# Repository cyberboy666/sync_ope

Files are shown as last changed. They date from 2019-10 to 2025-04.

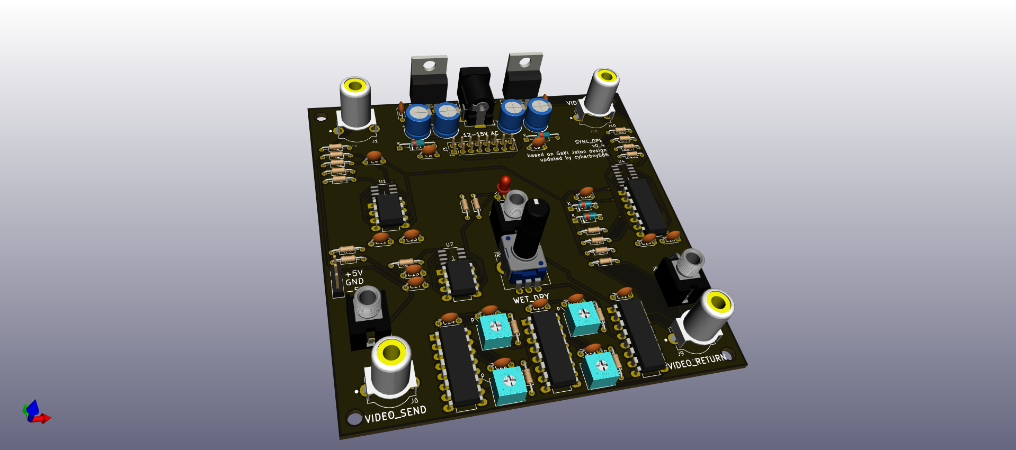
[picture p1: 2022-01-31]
sync_ope_3d.png

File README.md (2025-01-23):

# sync_ope

### effect send + sync restoring circuit - adapted from a gael jaton design



- this circuit is distributed by __UNDERSCORES__ - _an open video hardware label_ : it is available to purchase - as a pcb, kit or assembled unit - at [underscores.shop](https://underscores.shop/sync_ope/)
- the schematic for the circuit can be found [here](/hardware/schematic.pdf)
- the pcb gerber files for the lastest version can be found [here](/hardware/gerber_latest.zip)
- interactive BOM is [here](https://htmlpreview.github.io/?https://github.com/cyberboy666/sync_ope/blob/main/hardware/bom/ibom.html)
- consider [donating](https://opencollective.com/underscores) to the underscores project to help us continue creating for the commons

## description

_sync_ope_ is a companion circuit for analog glitch & circuit bent video instruments. it preserves the sync pulses from the original signal and allows for smooth mixing between clean (dry) and distorted (wet) video. preserving the sync pulses means the distorted video is less likely to drop out (blue screen) when sent to analog video decoders such as in projectors, capture cards and digital tvs

- __knob__ for physical control over dry/wet external effect
- __cv jack (0-1v)__ for sequenced control over dry/wet external effect
- external video send & return over rca or 3.5mm jacks

 __NOTE__ a 12v_dc power supply with 1.5A or greater is required to start the circuit

## demo video

(https://videos.scanlines.xyz/w/eyN4xfUZrG2YHyuf6rk1wZ)

# documentation

this project is fully _open-source hardware_ - all the files required to build it are included in this repo for free. if you have the time and/or skill you can contribute back by collaborating on / testing new designs, improving these docs, making demo videos/other creative content etc. you can also support the project financially by [donating](https://opencollective.com/underscores) directing, or purchasing through the [web shop](https://underscores.shop).

depending on whether you are going fully diy or buying an assembled and tested unit, some of the following guides will be relavent to you. the flow would be:

## ordering parts

<details><summary><b>parts sourcing guide (w/ notes on pcb fabracation )</b> - start here if you are building fully from scatch or have purchased a pcb</summary>

i try to source all the parts i can from either:
- [tayda](https://www.taydaelectronics.com/) ; cheaper for common parts like resistors etc, also good for mechanical parts like switches and buttons
- [mouser](https://www.mouser.de/) ; has lots more options, speciality video ic's, can sometimes cost more (free shipping on orders over 50euros)
- other ; ocationally there will be parts which will need to be sourced elsewhere - usually either aliexpress, ebay or amazon etc...

take a look at the [full_bom](/hardware/bom/full_bom.csv) for this project to see where i am sourcing each part from

## import into tayda

- go to the [tayda quick order](https://www.taydaelectronics.com/quick-order/) and in bottom corner choose _add from file_
- select the file [tayda_bom.csv](./hardware/bom/tayda_bom.csv) in the BOM folder (you will have to download it first or clone this repo)
- after importing select _add to cart_
- __NOTE:__ the minimum value for resistors is 10, so you may need to modify these values to add to cart (or if they are already modified here you will need to see the  full_bom for actual part QTY) 

- OPTIONAL: it is a good idea to add some dip-ic sockets and 2.54pin headers/sockets to your tayda order if you dont have them around already
  
## import into mouser

- go to [mouser bom tool](https://nz.mouser.com/Bom/) and click _upload spreadsheet_
- select the file [mouser_bom.csv](./hardware/bom/mouser_bom.csv) in this folder (you will have to download it first or clone this repo), then _upload my spreadsheet_ and _next_
- ensure that __Mouser Part Number__ is selected in the dropdown above the first row, then _next_, _process_
- if everything looks correct can now put _add to basket_

# ordering pcbs

you can support this project by buying individual pcbs from the [shop](https://underscores.shop). if you would rather have pcbs fabricated from gerbers directly the file you need is [here](/hardware/gerber_latest.zip)

- i get my pcbs fabricated from [jlcpcb](https://cart.jlcpcb.com/quote) - 5 is the minumum order per design
- upload the zip file with the `add gerber file` button
- the default settings are mostly fine - set the __PCB Qty__ and __PCB Color__ settings (you can check that the file looks correct with pcb veiwer)
- it may be best to combine orders with other pcbs you want to have fab'd since the shipping can cost more than the items - also orginising group buys is a good way to distribute the extra pcbs /costs 
  
i often use jlcpcb because they are reliable, cheap and give you an option of colours. remember though that the cheapest Chinese fab houses are not always the most ethical or environmently friendly - if you can afford it consider supporting local companies. 
  
</details>

## assembly guide
  
<details><summary><b>assembly guide</b> - start here if you have purchased a diy kit</summary>

## interactive BOM for build guiding

follow this link to view the [interactive BOM](https://htmlpreview.github.io/?https://github.com/cyberboy666/sync_ope/blob/main/hardware/bom/ibom.html)

## general solder advice

- remember to heat pad first (2-3seconds), then add solder, then continue to heat (1-2seconds)

- Checkout the web-comic [soldering is easy](https://mightyohm.com/files/soldercomic/FullSolderComic_EN.pdf) for more soldering advice

## smd or dip ic option
  
for some of the rarer ic's both smd and dip footprints are on the board - if you are assembling yourself you can choose which of these to source (dont place both!)
 - for the smd parts i would place and solder these first before doing any of the throughhole parts - please make sure these parts are placed facing __downwards__ as indicated on the silkscreen. you can test the continuity of your solder joints with a multimeter on the pin + one on the corresponding dip pad

## assemble guide

- Start by soldering the smallest parts first: resistors, diodes, capacitors and regulators - take note of the direction on the diodes : black bar on component matching black bar on footprint – I place about 10 components in and then solder and clip them
- Next lets do the ic’s/sockets - make sure the direction is correct! place in and fold two corner pins to hold in place, then solder all pins. you can place the ic in now too
- Finally solder in the interface parts: trim_pots & pots, jacks, power barrel. If you are using not using eurorack power supply there is no need to solder anything on j7 (or j3)

## blanking calibration

There is a total of 4 trimpots on the sync_ope board to calibrate the vertical and horizontal blanking pulses – __start by rotating all of them fully clockwise__

## calibrating with an osciloscope

If you have a two channel oscilloscope with edge trigger you can inspect the incoming video signal on one channel and the blanking pulse on the other (trigger on rising edge of this blanking pulse channel)

### calibrate v_blanking (RV3, RV5)

- set the scope width to about 1ms - test the edge detect works by probbing pin3 of u7_lm1881 this should lock the scrolling display to vblanking of the incoming video frame
- next hold pulse probe on _v_blanking_ (__pin10 of u6_hc4538__) - similar to above, the scrolling video should lock over blanking pulse trigger
- starting with top left trim (rv3) allign the rising edge of blanking pulse to the rising edge of video signal by turning rv3 counterclockwise
- next allign falling edge of blanking pulse to falling edge of video signal by turning rv5 counterclockwise

vblanking

### calibrating c_blanking (RV2, RV4):

- set scope width to about 10us - test the edge detect works by probing pin1 of u7_lm1881 this should lock the scrolling display to c_blanking of incoming video line
- next hold pulse probe on c_blanking (pin10 of u5_hc4538) - similar to above, the scrolling video should lock over blanking pulse trigger
- starting with top right trim (rv2) allign the rising edge of blanking pulse to the rising edge of video signal by turning rv2 counterclockwise
- next allign falling edge of blanking pulse to falling edge of video signal by turning rv4 counterclockwise

cblanking

## calibrating without an osciloscope

__start with all trim pots clockwise__ . plug in an effect and have sync_ope mix knob clockwise (wet): notice the square outline of the screen with the effect and the outer parts that are without - this is what we are trying to fill in:

vlcsnap-2022-09-24-21h25m09s377

starting v_blanking with top left - rv3 and then to rv5:

- watching top of screen turn rv3 counterclockwise until effect alligns with viewing area
- watching bottom of screen turn rv5 counterclockwise until effect alligns with viewing area

now c_blanking with top right - rv2 then rv4:

- watching left of screen turn rv2 counterclockwise until effect alligns with viewing area
- watching right of screen turn rv4 counterclockwise until effect alligns with viewing area
  
</details>

## operating guide
  
<details><summary><b>operating guide</b> - start here if you have purchased an assembled unit</summary>
  


- power the unit via the barrel jack with 12v_dc adapter - alternatively you can power it from the eurorack header or +-5v with the side power pins
- plug a composite video source (eg output from a camcorder) into the top left VIDEO_IN jack -> the middle led should light up when a video source input is detected
- plug a composite video display (eg an old tv or easycap capture card) into the top right VIDEO_OUT jack 
- now  with mix knob rotated fully anti-clockwise your source video should be passing through to the display
- plug one of the VIDEO_SEND jacks into the _input_ of your external processing device
- plug one of the VIDEO_RETURN jacks into the _output_ of your external processing device
- now with the mix knob rotated fully clockwise your source video should pass through the external effect device - but with stable sync pulses !
- if you have the gear for it you can sequence this mix knob using the cv jack above it - only the range 0-1v will respond - dont send it negative voltage.
  
## trim pot calibration for pal/ntsc
  
to calibrate the blanking intervals between pal and ntsc there are (rough) markings on the pcb to help you. for any given trimpot:

- rotate it all the way anticlockwise. from this position take the part of cross pointing south-west (7-8oclock) as reference and rotate clockwise until this reference is lined up with the marking (n for ntsc, p for pal)
- if you have an oscilloscope you can calibrate more precisely by connecting the scope inputs to pins 10 of U6 and 10 of U5
- you can also try to calibrate blanking by eye - setting it roughly to the markers and then moving the trimpots slightly to see what happens.

[pic coming soon]

</details>

### more info

<details><summary><b>how the circuit works</b></summary>
  
[coming soon]

</details>

<details><summary><b>contributing guide</b></summary>
  
if you would like to contribute back to these projects in some way but dont know how the best thing (for now) would be to reach out to me directly ( tim@cyberboy666.com or @cyberboy666 on scanlines forum) - i will be happy to help
  
</details>

## credits & more info

This circuit is distributed through UNDERSCORES – open video hardware label – visit [underscores.shop](https://underscores.shop) for more info

The pcb was designed using KICAD , the booklet was created in LibreOffice Draw

Everything from gerbers, cad files, panels and documentation is freely available online and distributed under CC-BY-SA / open-source licenses – help us contribute to the commons !

Ask any questions or start discussions related to this project on the [scanlines.xyz](https://scanlines.xyz) forum – an online community space dedicated to diy av / electronic media art

You can contact me directly at tim (at) cyberboy666 (dot) com 
Please get in touch if you are interested in hosting a workshop !



Thanks to Gael Jaton for sharing your designs and knowledge. to Bastien Lavaud for circuit advice, always. To Guergana Tzatchkova for booklet design inspiration. To Ben Caldwell for project advice. To everyone who has or will contribute ♥♥♥

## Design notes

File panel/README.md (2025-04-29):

# enclosure guide

we now offer ~~two~~ one kind of enclosures for this project:

- __stand-alone enclosure__ - made from a front and back panel, plus screws and standoffs



- ~~__eurorack enclosure__ - made from just a front panel, plus screws and standoffs to mount in a eurorack case~~

currently not offering sync_ope eurorack panels due to [this issue](https://github.com/cyberboy666/sync_ope/issues/9) with circuit requiring >1.5A to start the rails - which is more than many eurorack supplies can give. instead i am working on an improved eurorack version of this circuit - coming soon!

you can support these projects by getting enclosure kits directly through [underscores.shop](https://underscores.shop) - [standalone](https://underscores.shop/product/standalone-enclosure-kit-for-sync_ope/) - _if ordered with an assembled unit we will also assemble the enclosure for you also_

# diy part sourcing

## panel fabrication

included in this repo are the cad files needed to create your own panels. they are designed in kicads pcbnew - so open the `.kicad_pcb` file to edit them directly. 

you can also use the exported `gerber` files (here they are combined in `.zip`) to get panels fabricated in __fr4__ at a pcb house like the ones we sell. (these usually have a minimum order of 5 or 10)  

another option for diy fabrication is using a lasercutter to cut the panels in wood or acrylic. this is what i do when prototyping panels so you should find some exports in `svg` or `dxf` that are laser ready. _note that the `edgecut` layer is for cutting out and the `silkscreen` layer is for the panel markings. you may need to edit these files or export directly from pcbnew to suit the cutter you are using_

it would also be possible to import these panel files into a sketch in 3d cad program like __freecad__ to create a 3d enclosure for 3d printing... however this is not something i have files prepared for

## 3d printing

i use some custom modelled switch and pot caps for my enclosure kits. you can print these yourself or upload them to a 3d printing fabrication service.

## enclosure kit BOM

things like screws and standoffs can be sourced from lots of places. i will link my source as an example although these links often expire. you could even 3d print your own standoffs from the _id/od_ and length (inner diameter 3.2mm, outer diameter 5mm)

### standalone enclosure

item | source
--- | ---
Front panel | [sync_ope_default_panel_for_v1_0_1_mk_ii.zip](https://github.com/cyberboy666/sync_ope/blob/main/panel/default_panel/sync_ope_default_panel_for_v1_0_1_mk_ii.zip)
Back panel | [back_panel.zip](https://github.com/cyberboy666/sync_ope/blob/main/panel/back_panel/back_panel.zip)
Rubber feet x4 | [aliexpress](https://www.aliexpress.com/item/1005005287385986.html?pdp_ext_f=%7B%22sku_id%22:%2212000032498489269%22%7D)
Pot cap x1 | 3d printed from [stl file](https://github.com/cyberboy666/enclosure_kit_commons/blob/main/cap_pot_6mm_shaft/cap_pot_star_single_r2.8.stl)
M3-25mm screw x4 | [aliexpress](https://www.aliexpress.com/item/1005002364189187.html?pdp_ext_f=%7B%22sku_id%22:%2212000020354274907%22%7D)
M3 nut x4 | [aliexpress](https://www.aliexpress.com/item/1005007502691265.html?pdp_ext_f=%7B"sku_id":"12000041089836836"%7D)
m3-13mm standoff x4 (front) | [aliexpress](https://www.aliexpress.com/item/1005003086579258.html?pdp_ext_f=%7B"sku_id":"12000023995222164"%7D)
m3-5mm standoff x4 (back) | [aliexpress](https://www.aliexpress.com/item/1005003086579258.html?pdp_ext_f=%7B"sku_id":"12000023995222156"%7D)

## enclosure assembling

these enclosures are assemlbed by creating a stack of front-panel -> circuit -> back-panel using the screws and standoffs. where the front standoffs go between front panel and pcb and back standoff go between back panel and pcb. the m3 hex holds it together from the bottom.

i find it easiest to hold circuit on its side and work around one screw at a time:

- first place the front standoff between front panel and pcb
- then put the screw through holding them together
- next place back standoff on screw followed by back panel and hex
- then repeat for other 3 corners

tweezers can be helpful to pick and place the standoffs and also to tighten the m3 hexs

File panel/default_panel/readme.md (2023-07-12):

# sync_ope default_panel notes

- the mounting holes fit m3 screws
- 25mm screws will fit front_panel, pcb and back_plate
- the front_panel mounts to pcb with 12mm standoffs
- will need to lie large caps and regulators down to fit panel
- blanking calibration trimpots can still be set with tool such as screwdriver
- the default potentiometers in underscores BOMs have 12mm shaft lengths - consider replacing these with >17mm shaft length alternatives if you plan to use it with a panel

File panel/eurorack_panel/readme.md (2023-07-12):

# sync_ope eurorack_panel notes

- the mounting holes fit m3 screws
- the front_panel mounts to pcb with 12mm standoffs
- will need to lie large caps and regulators down to fit panel
- blanking calibration trimpots can still be set with tool such as screwdriver
- this circuit has footprint for eurorack power header to be soldered to bottom of pcb
- this panel is 20HP
- the default potentiometers in underscores BOMs have 12mm shaft lengths - consider replacing these with >17mm shaft length alternatives if you plan to use it with a panel

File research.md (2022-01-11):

# research

# inital idea and brainstorm

### "real-time-analog-video-send-return-sync-restoring-mixer"

Sync-Ope is an analog video circuit project for sync signal stripping, hard glitch visible signal, mixing dry/wet signal and sync restoring.
Work for both with NTSC/PAL video signals. Dev discussion thread here : https://scanlines.xyz/t/sync-ope-sync-restoring-circuit-next-revision-ideas  

This act as a "video inserter"/ TBK (time base keeper). Basically it split video signal input between 'pulseSync+burst' and visible lignes signal , then sum its before provide video out. It allow to hard glitch the visible signal (with custom passive and active circuits, mechanical switching, body contact, analog guitar effects...) without touching sync part. It's design around a LM1881 sync separator and a LT1251CN CV mixer which allow a kind of "dry/wet" knob and control voltage from video/audio modules (0 to 1V scale).  
video send/receive connexions act as a send/return loop to input/output your custom effect circuit.  
For more details on construction, please see README file of KiCad folder : https://github.com/gaeljaton/Sync-Ope/tree/master/kicad-files  
  
STATUT :   
-Schematic ok 
-general tests ok  
-PCB V.0.2 NEED REV!    
  
TODO :  
*Stress tests of limiting diodes at video receive (return) inlet, searching for better components (x3 fast diodes 0.7V reversed instead of the zener 1.8V, lower Vdrop for Schottky diode ?)  
*better clamping to blanking level design, actual one crush a bit the burst! affecting colors... => LOGIC GATE DELAY SIGNAL (based CD4069 hex inverter -tested OK!)   
*Negative voltage protection to CV input mixer J5  
*tutorial/review videos  
*PCB design V.0.3 (smaller version - 80x80mm, remove "video send" grounded when unplugged)  
*Eurorack module version, all in line design, 4 to 6 HP

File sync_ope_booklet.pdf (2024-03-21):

### cyberboy666 & underscores.shop present a circuit adapted from gael jaton design

# sync_ope

## effect send and sync restoring circuit

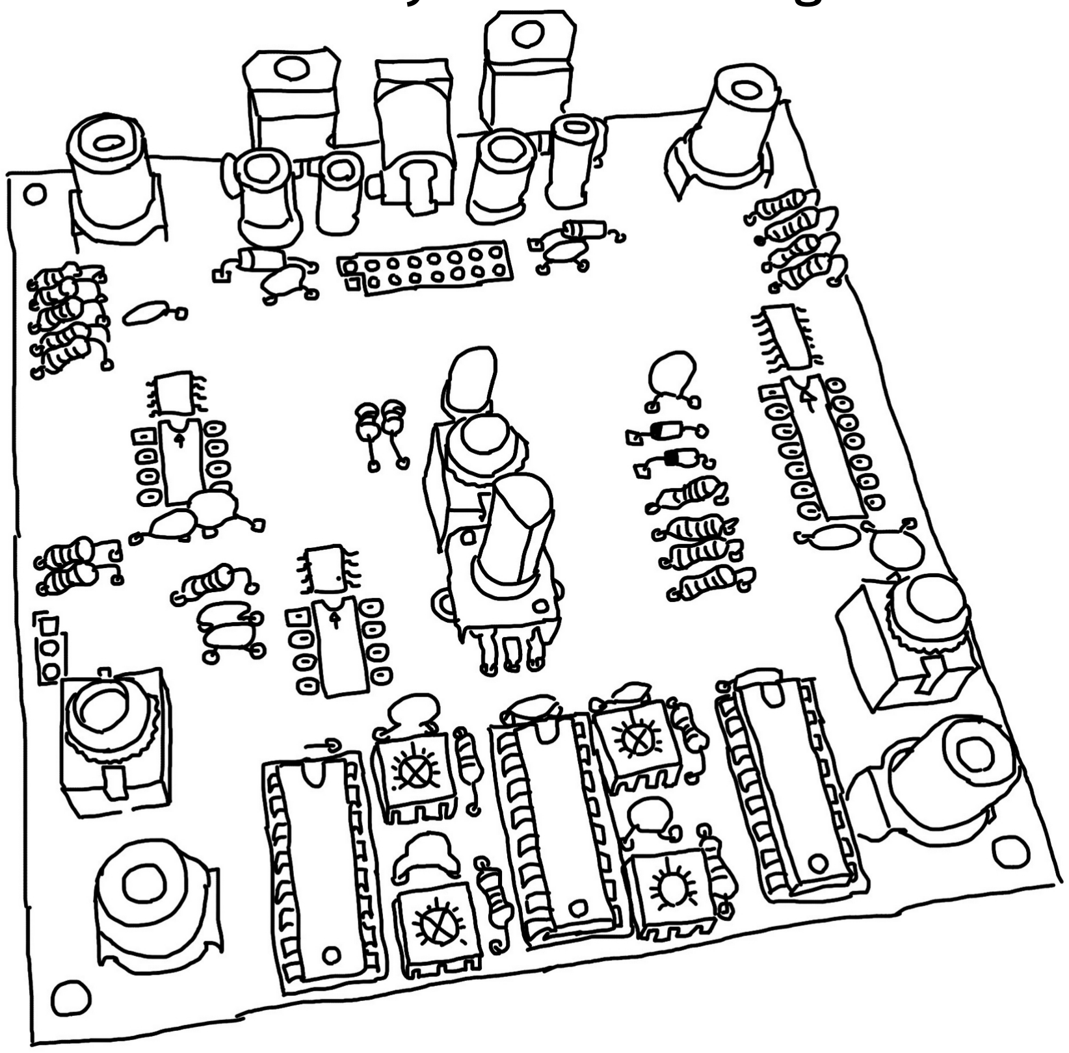
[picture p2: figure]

## instruction manual and build guide

## V1_1_0

View this project online at underscores.shop/sync_ope

# DESCRIPTION

sync_ope is a companion circuit for analog glitch & circuit bent video instruments. it preserves the sync pulses from the original signal and allows for smooth mixing between clean (dry) and distorted (wet) video.

preserving the sync pulses means the distorted video is less likely to drop out (blue screen) when sent to analog video decoders such as in projectors, capture cards and digital tvs

features

- knob for physical control over dry/wet external effect
- cv jack (0-1v) for sequenced control over dry/wet external effect
- external video send & return over rca or 3.5mm jacks

composite
video input

composite
video output

12v dc power input

(2.1mm barrel center positive)

external
effect send
(over 3.5mm
or rca jack)

external

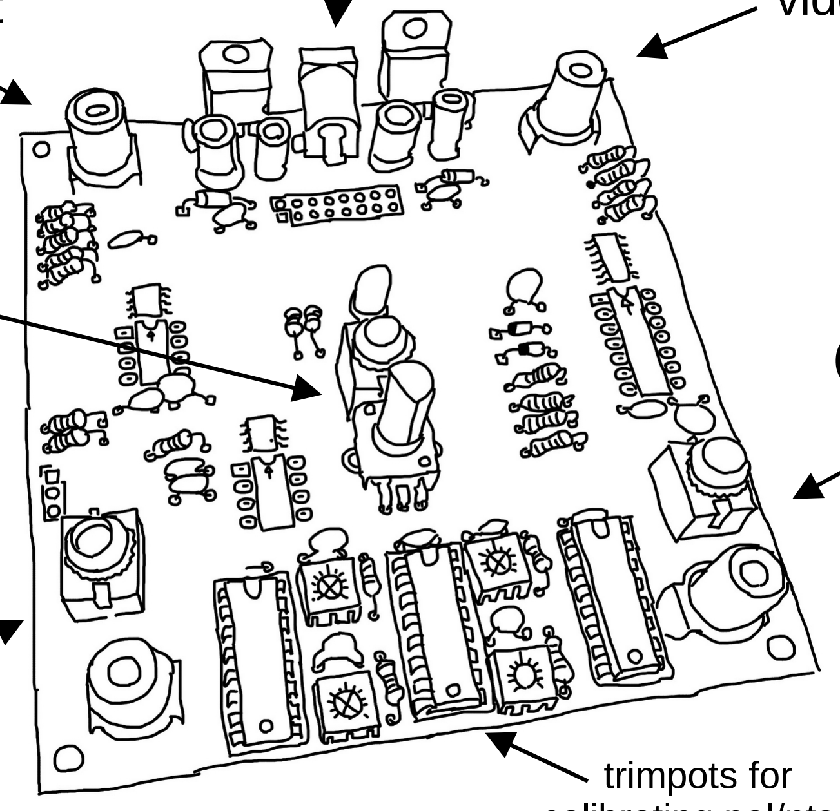
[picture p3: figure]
trimpots for

effect return
(over 3.5mm
or rca jack)

knob and cv
control over
dry/wet
external effect

calibrating pal/ntsc

# BACKGROUND

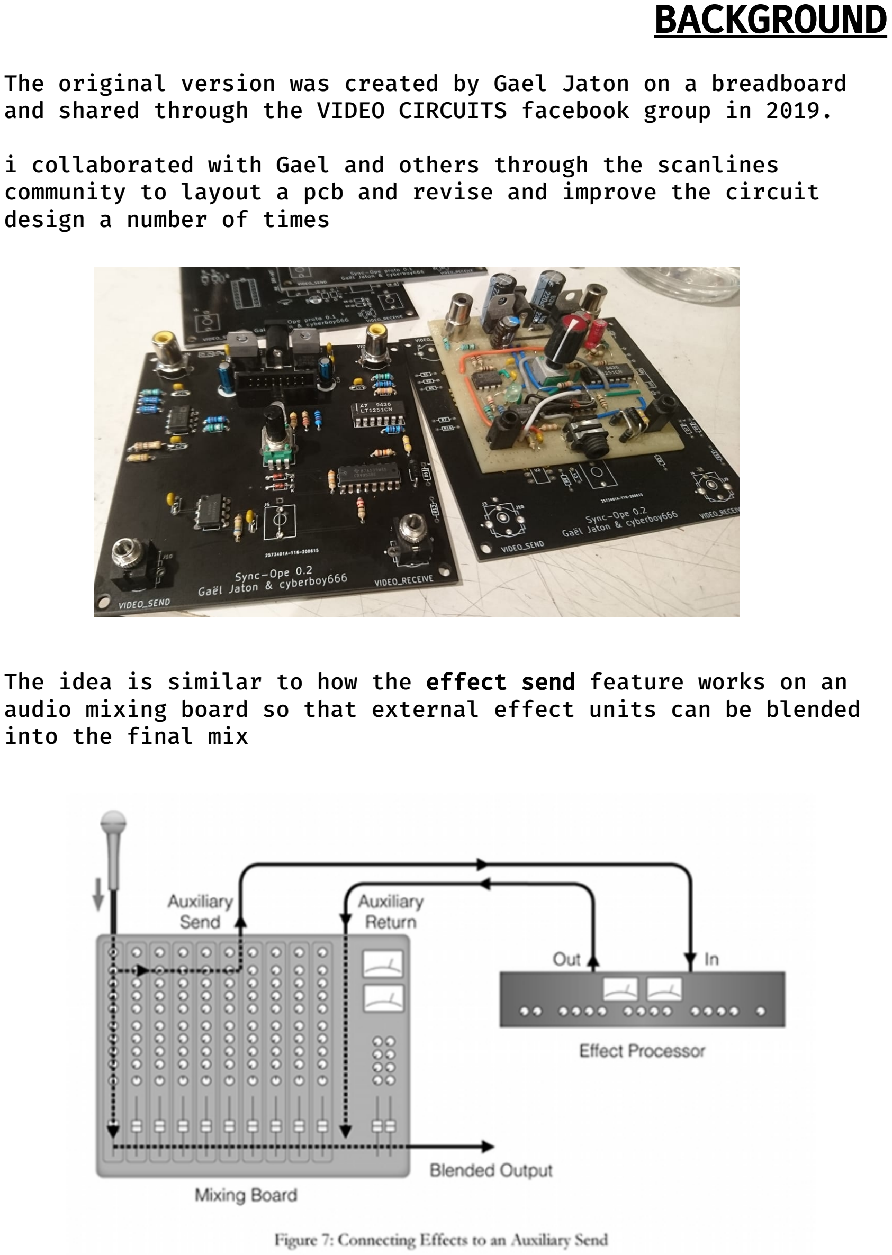
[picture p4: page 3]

The original version was created by Gael Jaton on a breadboard and shared through the VIDEO CIRCUITS facebook group in 2019.

i collaborated with Gael and others through the scanlines community to layout a pcb and revise and improve the circuit design a number of times

The idea is similar to how the effect send feature works on an audio mixing board so that external effect units can be blended into the final mix

# OPERATING INSTRUCTIONS

Power supply

This circuit needs +5v & -5v to operate. As of v1_0_0 there is circuitry on the board to convert standard 12vdc power input from barrel jack to this format. Alternatively if you are using eurorack it can take this +12v directly from this rail

Older versions <= v0_5_1 of the circuit needed 12-15v AC input on the power barrel_jack to generate the +-5v supplies

Connecting ins, outs & the external effect

- plug your composite video source (eg output from a camcorder) into the top left VIDEO_IN jack -> the middle led should light up when a video source input is detected
- Connect your composite video display (eg an old tv or easycap capture card) into the top right VIDEO_OUT jack - now with mix knob rotated fully anti-clockwise your source video should be passing through to the display
- plug one of the VIDEO_SEND jacks into the input and one of the VIDEO_RETURN jacks from the output of your external processing device
- now with the mix knob rotated fully clockwise your source video should pass through the external effect device - but with stable sync pulses !
- if you have the gear for it you can sequence this mix knob using the cv jack above it - 0-1v will cover full range - dont send it negative voltage.

blanking calibration

There is a total of 4 trimpots on the sync_ope board to calibrate the vertical and horizontal blanking pulses – start by rotating all of them fully clockwise

If you have a two channel oscilloscope with edge trigger you can inspect the incoming video signal on one channel and the blanking pulses on the other (see j11 for blanking breakout pins)

Starting from top-left and working down - first slowly turn the trim pots counterclockwise until the rising and falling edges align with blanking on the video signal

If you do not have a scope you can roughly calibrate
In same way by looking at the video output with effect knob fully on – for each pot align effect with an edge of screen: RV3 – top, RV4 – bottom, RV2 left, RV4 right

Find more info for calibration on project github page

wet effect

dry effect

wet effect

# BUILD INSTRUCTIONS

It is highly recommended to use the interactive BOM to help with placement on this build – type kutt.it/ElOPGl into a browser or find the links from the github page

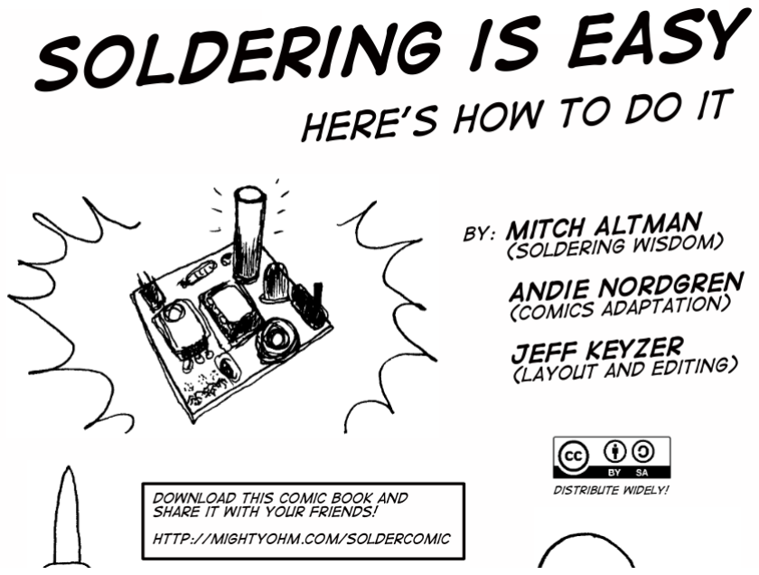
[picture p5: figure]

smd or dip ic option

for some of the rarer ic's both smd and dip footprints are on the board - if you are assembling yourself you can choose which of these to source (dont place both!)

for the smd parts i would place and solder these first before doing any of the throughhole parts - please make sure these parts are placed facing downwards as indicated on the silkscreen. you can test the continuity of your solder joints with a multimeter on the pin + one on the corresponding dip pad

assembling

- Start by soldering the smallest parts first: resistors, diodes, capacitors and regulators - take note of the direction on the diodes : black bar on component matching black bar on footprint – I place about 10 components in and then solder and clip them
- Next lets do the ic’s/sockets - make sure the direction is correct! place in and fold two corner pins to hold in place, then solder all pins. you can place the ic in now too
- Finally solder in the interface parts: trim_pots & pots, jacks, power barrel. If you are not using eurorack power supply there is no need to solder anything on j7 (or j3) note on soldering: remember to heat pad first (2-3seconds), then add solder, then continue to heat (1-2seconds)

Checkout the web-comic
soldering is easy for more soldering advice

# HOW THE CIRCUIT WORKS

A composite video signal is made up of two parts:

visible image data - which tell the tv at any given point how bright the image should be

sync & blanking data – offscreen pulses which help the tv align new lines and frames so they are in sync with each other

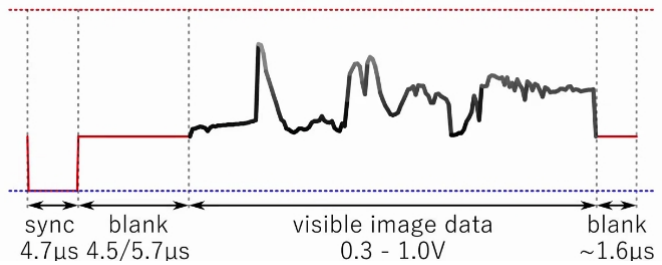
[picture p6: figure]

A digital video display will load this analog signal into its buffer – and needs the sync & blanking to do this correctly. If the sync & blanking pulse is corrupted then it will ‘blue screen’ and show nothing

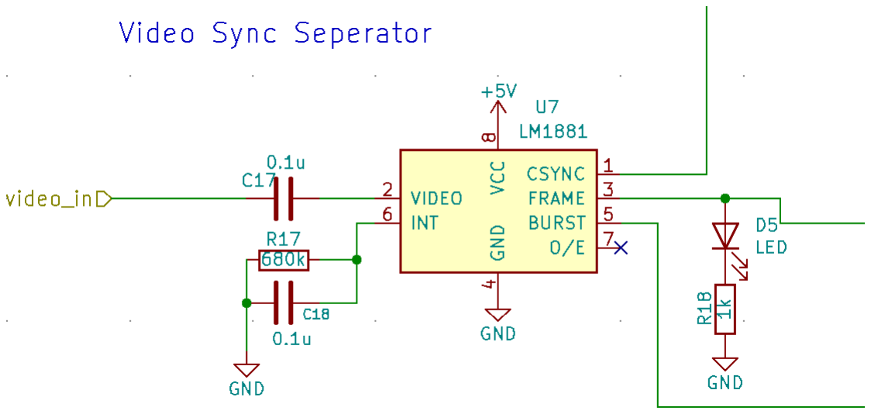
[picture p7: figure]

LM1881 is a video ic that can separate the sync & blanking part of the video signal

# HOW THE CIRCUIT WORKS CONTINUED

LT1251 is a video crossfader ic that creates an output signal as a mix between two inputs (A & B).

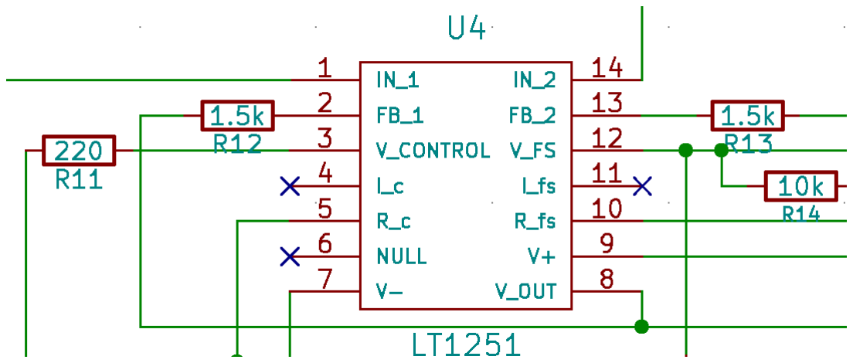
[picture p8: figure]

Output from the sync detecting ic is used to set the ‘crossfader’ position of video output – when video signal is in sync & blanking range the output will use the clean signal (A) – this ensures that no matter how corrupted the visible image data becomes, the sync & blanking data of the output video signal will always be clean

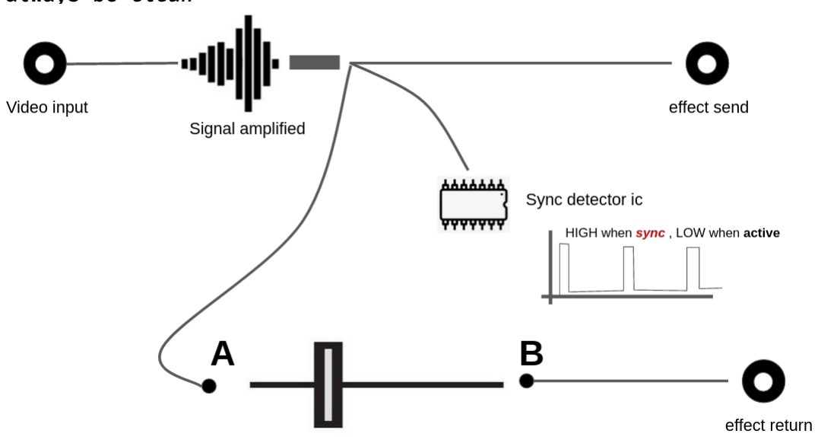
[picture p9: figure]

Then when signal is in the visible image range the knob/cv jack will position the crossfader between A and B (ie decide how much of clean vs wet signal to show in visible image)

# CREDITS AND MORE INFO

This circuit is distributed through UNDERSCORES – open video hardware label – visit underscores.shop for more info

The pcb was designed using KICAD , this booklet was created in LibreOffice Draw

Everything from gerbers, cad files, panels and documentation is freely available online and distributed under CC-BY-SA / open-source licenses – help us contribute to the commons !

Ask any questions or start discussions related to this project on the scanlines.xyz forum – an online community space dedicated to diy av / electronic media art

You can contact me directly at tim (at) cyberboy666 (dot) com Please get in touch if you are interested in hosting a workshop !

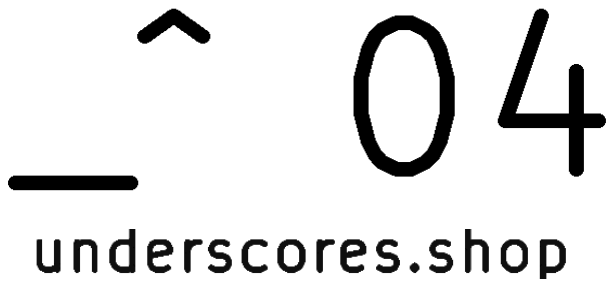
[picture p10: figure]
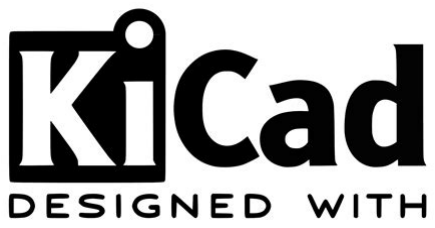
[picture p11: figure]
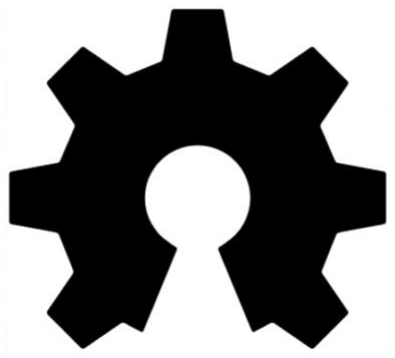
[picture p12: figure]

Thanks to Gael Jaton for sharing your design and knowledge. to Bastien Lavaud for circuit advice, always. To Guergana Tzatchkova for booklet design inspiration. To Ben Caldwell for project advice. To everyone who has or will contribute ♥♥♥

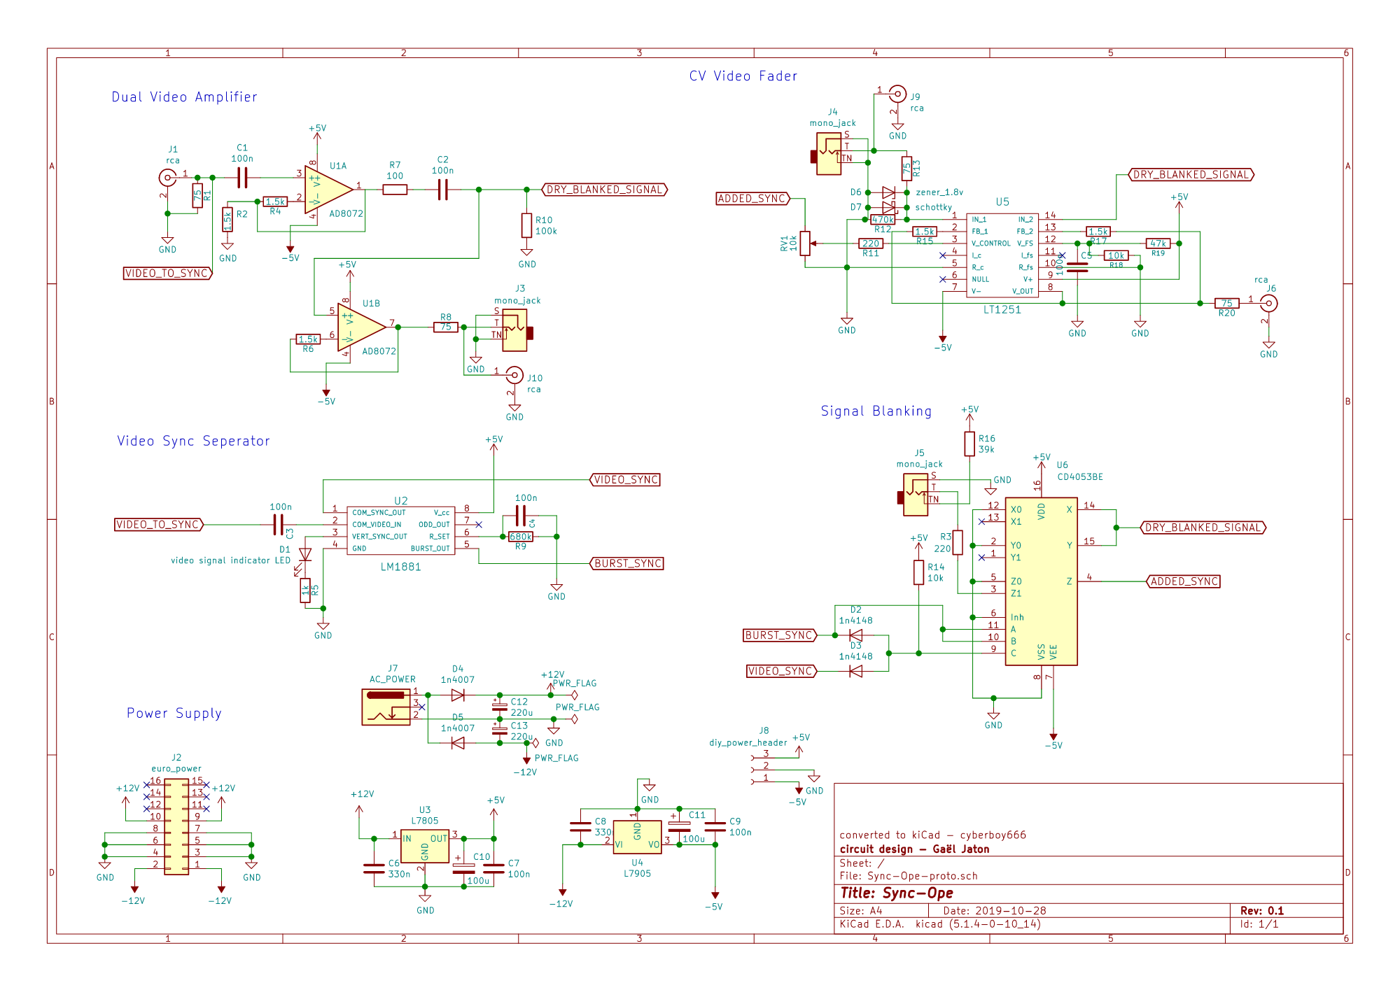
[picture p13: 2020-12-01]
schV01.png

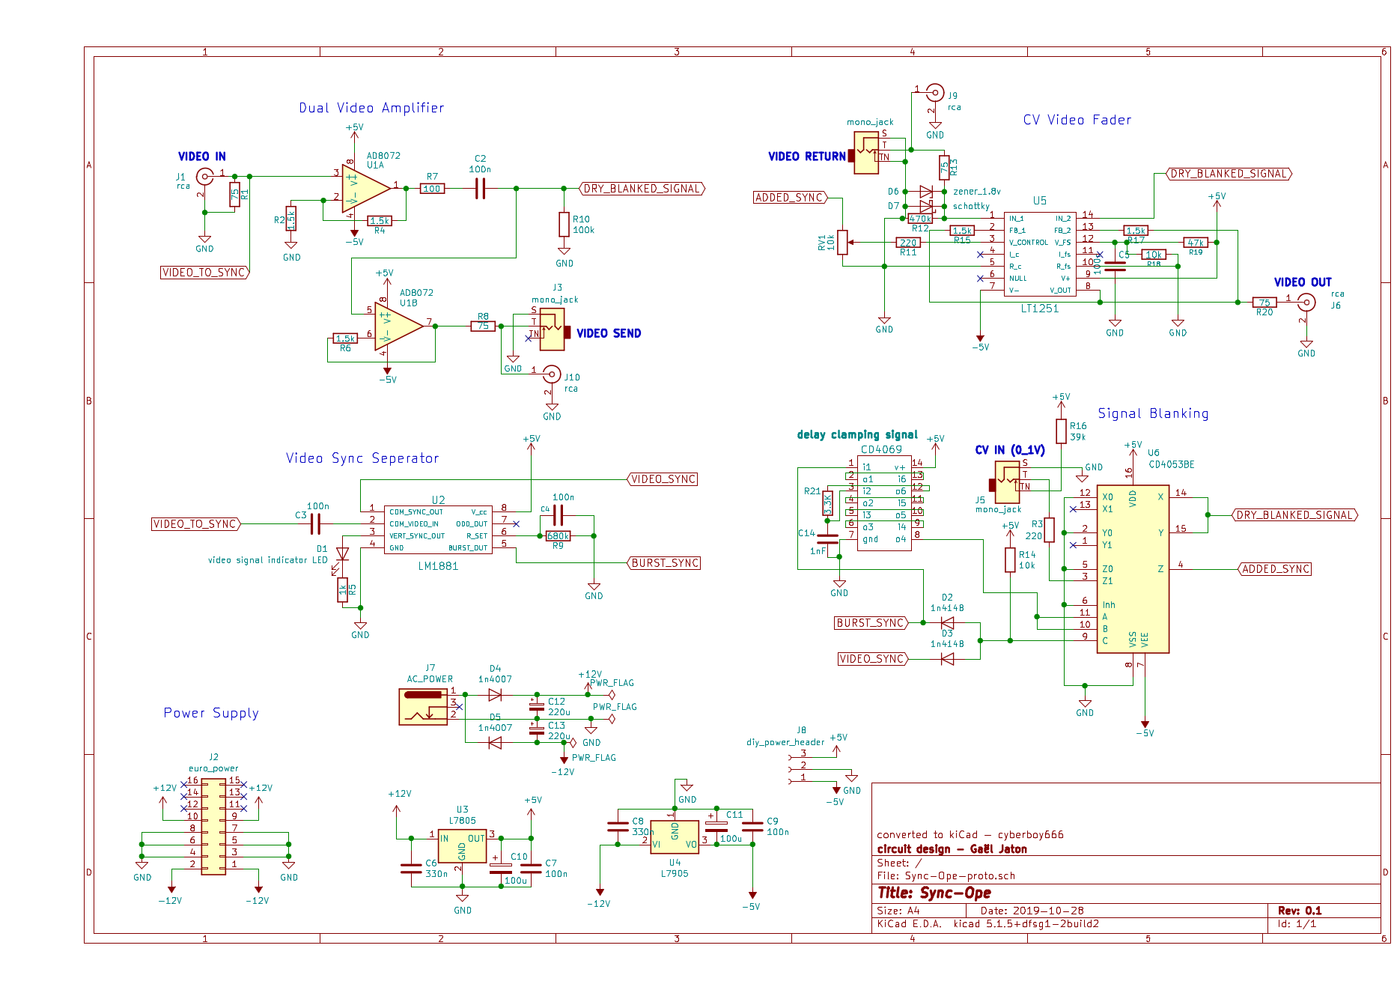
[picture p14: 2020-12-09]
schV02.png

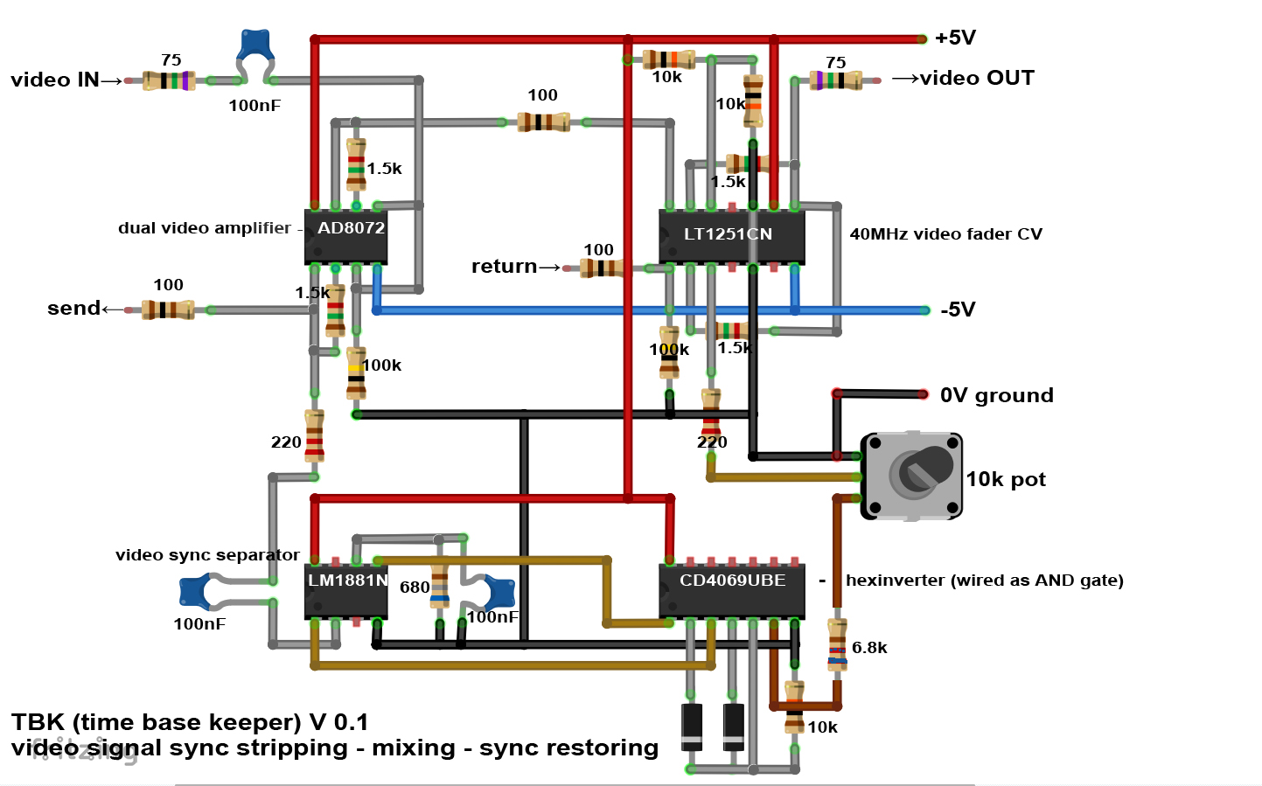
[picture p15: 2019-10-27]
TBK01.jpg

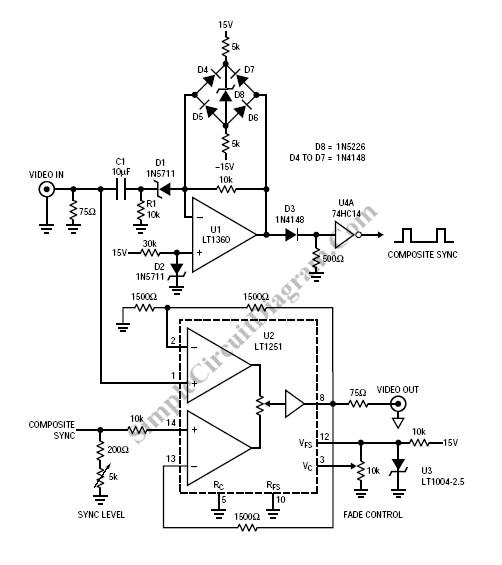
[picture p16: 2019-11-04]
video_circuits_exemples/video-fader-circuit.gif

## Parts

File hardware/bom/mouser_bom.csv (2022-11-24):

sku | qty | ref | val | vendor
610-1N4614TRPB | 1 | D3 | zener_1.8v | mouser
490-RCJ-024 | 4 | J1 J6 J9 J10 | rca | mouser
584-AD8072JNZ | 1 | U1 | AD8072 | mouser
863-LM2575T-5G | 2 | U2 U3 | LM2575-5.0BT | mouser
584-LT1251CN#PBF | 1 | U4 | LT1251 | mouser
595-CD74HC4538E | 2 | U5 U6 | 74HC4538 | mouser
926-LM1881MX/NOPB | 1 | U7 | LM1881 | mouser

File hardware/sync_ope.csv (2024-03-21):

Reference | Quantity | Value | Footprint | Datasheet
C1 | 1 | 220u | Capacitor_THT:CP_Radial_D5.0mm_P2.50mm
C19 C21 | 2 | 1nf_poly | Capacitor_THT:C_Disc_D4.3mm_W1.9mm_P5.00mm
C2 C3 | 2 | 2200u | Capacitor_THT:CP_Radial_D13.0mm_P5.00mm
C20 | 1 | 0.1u_poly | Capacitor_THT:C_Disc_D4.3mm_W1.9mm_P5.00mm
C22 | 1 | 1uf_poly | Capacitor_THT:C_Disc_D4.3mm_W1.9mm_P5.00mm
C4 C10 C11 C12 C13 C14 C15 C16 C17 C18 C23 C24 C25 | 13 | 0.1u | Capacitor_THT:C_Disc_D4.3mm_W1.9mm_P5.00mm
D1 D2 | 2 | 1n5819 | Diode_THT:D_DO-41_SOD81_P7.62mm_Horizontal
D3 | 1 | zener_1.8v | Diode_THT:D_DO-35_SOD27_P7.62mm_Horizontal
D5 | 1 | LED | LED_THT:LED_D3.0mm
D6 D8 | 2 | bat46 | Diode_THT:D_DO-35_SOD27_P7.62mm_Horizontal
D7 | 1 | 1n4007 | Diode_THT:D_DO-35_SOD27_P10.16mm_Horizontal
J1 J6 J9 J10 | 4 | rca | lib_fp:tht_vertical_rca
J11 | 1 | Conn_01x02 | Connector_PinHeader_2.54mm:PinHeader_1x02_P2.54mm_Vertical
J2 | 1 | barrel_jack | lib_fp:BarrelJack_Horizontal
J3 | 1 | europower | Connector_PinHeader_2.54mm:PinHeader_2x08_P2.54mm_Vertical
J4 J5 J8 | 3 | mono_jack_3.5mm | lib_fp:Jack_3.5mm_QingPu_WQP-PJ398SM_Vertical_CircularHoles
J7 | 1 | diy_power_header | Connector_PinHeader_2.54mm:PinHeader_1x03_P2.54mm_Vertical
L1 L2 | 2 | 100uH | Inductor_THT:L_Radial_D10.0mm_P5.00mm_Neosid_SD12k_style3
R1 R9 R16 | 3 | 75 | Resistor_THT:R_Axial_DIN0204_L3.6mm_D1.6mm_P7.62mm_Horizontal
R10 | 1 | 470k | Resistor_THT:R_Axial_DIN0204_L3.6mm_D1.6mm_P7.62mm_Horizontal
R11 | 1 | 220 | Resistor_THT:R_Axial_DIN0204_L3.6mm_D1.6mm_P7.62mm_Horizontal
R14 R19 | 2 | 10k | Resistor_THT:R_Axial_DIN0204_L3.6mm_D1.6mm_P7.62mm_Horizontal
R15 | 1 | 47k | Resistor_THT:R_Axial_DIN0204_L3.6mm_D1.6mm_P7.62mm_Horizontal
R17 | 1 | 680k | Resistor_THT:R_Axial_DIN0204_L3.6mm_D1.6mm_P7.62mm_Horizontal
R18 | 1 | 1k | Resistor_THT:R_Axial_DIN0204_L3.6mm_D1.6mm_P7.62mm_Horizontal
R2 R4 R5 R12 R13 | 5 | 1.5k | Resistor_THT:R_Axial_DIN0204_L3.6mm_D1.6mm_P7.62mm_Horizontal
R20 | 1 | 15k | Resistor_THT:R_Axial_DIN0204_L3.6mm_D1.6mm_P7.62mm_Horizontal
R21 | 1 | 68k | Resistor_THT:R_Axial_DIN0204_L3.6mm_D1.6mm_P7.62mm_Horizontal
R22 | 1 | 12k | Resistor_THT:R_Axial_DIN0204_L3.6mm_D1.6mm_P7.62mm_Horizontal
R3 | 1 | 510 | Resistor_THT:R_Axial_DIN0204_L3.6mm_D1.6mm_P7.62mm_Horizontal
R6 | 1 | 100 | Resistor_THT:R_Axial_DIN0204_L3.6mm_D1.6mm_P7.62mm_Horizontal
R8 | 1 | 39k | Resistor_THT:R_Axial_DIN0204_L3.6mm_D1.6mm_P7.62mm_Horizontal
RV1 | 1 | 10k_pot | lib_fp:Potentiometer_Vertical_Large
RV2 | 1 | 5k_trim | lib_fp:tht_vertical_trim_3362
RV3 RV5 | 2 | 20k_trim | lib_fp:tht_vertical_trim_3362
RV4 | 1 | 10k_trim | lib_fp:tht_vertical_trim_3362
U1 | 1 | AD8072 | lib_fp:DIP-SOIC-8
U2 U3 | 2 | LM2575-5.0BT | Package_TO_SOT_THT:TO-220-5_Vertical | http://ww1.microchip.com/downloads/en/DeviceDoc/lm2575.pdf
U4 | 1 | LT1251 | lib_fp:DIP+SOIC_14
U5 U6 | 2 | 74HC4538 | Package_DIP:DIP-16_W7.62mm_LongPads | https://assets.nexperia.com/documents/data-sheet/HEF4538B.pdf
U7 | 1 | LM1881 | lib_fp:DIP-SOIC-8
U8 | 1 | 74HC4053 | Package_DIP:DIP-16_W7.62mm_LongPads | http://www.ti.com/lit/ds/symlink/cd4052b.pdf

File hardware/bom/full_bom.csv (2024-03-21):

sku | qty | ref | val | vendor
A-4503 | 1 | C1 | 220u | tayda
A-1987 | 2 | C19 C21 | 1nf_poly | tayda
A-4526 | 2 | C2 C3 | 2200u | tayda
A-564 | 1 | C20 | 0.1u_poly | tayda
A-321 | 1 | C22 | 1uf_poly | tayda
A-4008 | 13 | C4 C10 C11 C12 C13 C14 C15 C16 C17 C18 C23 C24 C25 | 0.1u | tayda
A-484 | 2 | D1 D2 | 1n5819 | tayda
610-1N4614TRPB | 1 | D3 | zener_1.8v | mouser
A-3005 | 1 | D5 | LED | tayda
A-1095 | 2 | D6 D8 | bat46 | tayda
A-155 | 1 | D7 | 1n4007 | tayda
490-RCJ-024 | 4 | J1 J6 J9 J10 | rca | mouser
- | 1 | J11 | Conn_01x02 | -
A-4118 | 1 | J2 | barrel_jack | tayda
A-2956 | 1 | J3 | europower | tayda
A-2563 | 3 | J4 J5 J8 | mono_jack_3.5mm | tayda
- | 1 | J7 | diy_power_header | -
A-5503 | 2 | L1 L2 | 100uH | tayda
A-2193 | 3 | R1 R9 R16 | 75 | tayda
A-2180 | 1 | R10 | 470k | tayda
A-2246 | 1 | R11 | 220 | tayda
A-2203 | 2 | R14 R19 | 10k | tayda
A-2279 | 1 | R15 | 47k | tayda
A-2192 | 1 | R17 | 680k | tayda
A-2200 | 1 | R18 | 1k | tayda
A-2202 | 5 | R2 R4 R5 R12 R13 | 1.5k | tayda
A-2182 | 1 | R20 | 15k | tayda
A-2334 | 1 | R21 | 68k | tayda
A-2327 | 1 | R22 | 12k | tayda
A-2621 | 1 | R3 | 510 | tayda
A-2245 | 1 | R6 | 100 | tayda
A-2313 | 1 | R8 | 39k | tayda
A-5531 | 1 | RV1 | 10k_pot | tayda
A-610 | 1 | RV2 | 5k_trim | tayda
A-608 | 2 | RV3 RV5 | 20k_trim | tayda
A-604 | 1 | RV4 | 10k_trim | tayda
584-AD8072JNZ | 1 | U1 | AD8072 | mouser
863-LM2575T-5G | 2 | U2 U3 | LM2575-5.0BT | mouser
584-LT1251CN#PBF | 1 | U4 | LT1251 | mouser
595-CD74HC4538E | 2 | U5 U6 | 74HC4538 | mouser
926-LM1881MX/NOPB | 1 | U7 | LM1881 | mouser
A-028 | 1 | U8 | 74HC4053 | tayda

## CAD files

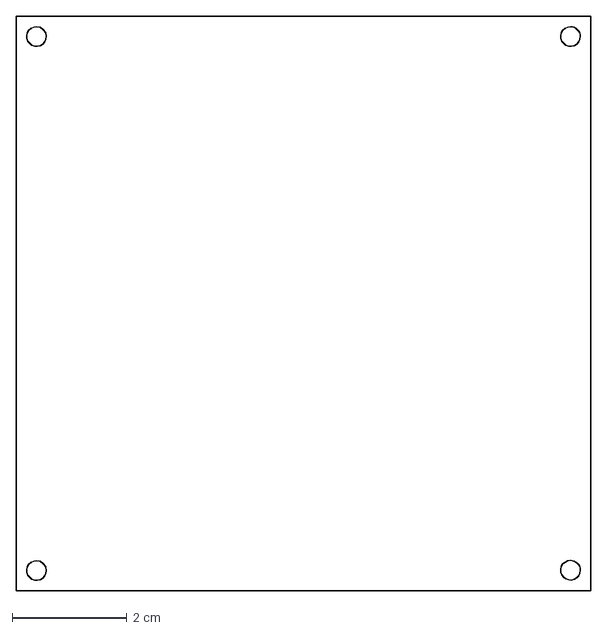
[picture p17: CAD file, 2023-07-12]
panel/back_panel/back_panel-Edge_Cuts.dxf
10.0 x 10.0 cm

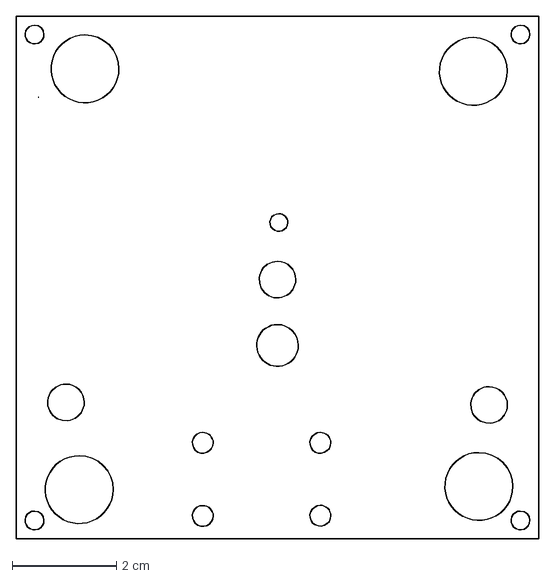
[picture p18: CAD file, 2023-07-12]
panel/default_panel/default_panel-Edge_Cuts.dxf
10.0 x 10.0 cm

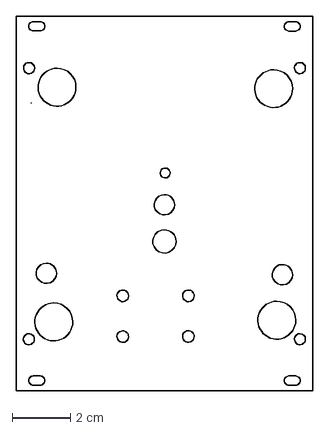
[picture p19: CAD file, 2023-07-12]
panel/eurorack_panel/eurorack_panel-Edge_Cuts.dxf
10.2 x 12.9 cm

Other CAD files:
panel/default_panel/default_panel-F_Silkscreen.dxf
panel/eurorack_panel/eurorack_panel-F_Silkscreen.dxf

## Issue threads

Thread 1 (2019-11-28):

suggestion : repo name change ?

langolierz, 2019-11-28:
just a suggestion that the repo title could be changed to "Sync-Ope" , while "analog-video-sync-stripper-injector-mixer" can be in the repo's subtitle.

usually github repos dont describe the project in the repo name, this is what the subtitle and readme is good for + makes it easier to share and remember the link . 😊

gaeljaton, 2019-12-09:
yes, you're right!

langolierz, 2019-12-10:
😅

Closed 2019-12-10.

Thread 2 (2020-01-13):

update board design from proto0.1

langolierz, 2020-01-13:
all the things to change for the next revision should go here :

redesign component placements so :
- no / less long tracks
- no long parallel tracks or closed side ducts
- power plug (with regulators) at top of circuit - closer together

langolierz, 2020-03-07:
more things to fix for next revision:

- reseistor footprints are a little tight (too small holes)
- some r values are not so well grouped (r3)
- 0.1u caps abit too spaced ,( shoild be placed closer to the power pins ?)
- not obvious which way the led goes

- power regulators should be other way round (metal back facing down)
- rca input/output footprints need outer ring connected to ground
- maybe should have an option of rca or 3.5mm for the send return ?

langolierz, 2020-06-13:
addressed these in the v0.2 design

Closed 2020-06-13.

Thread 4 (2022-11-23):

checklist of updates to make for major version update to this project

cyberboy666, 2022-11-23:
im making the first _major_ version update for any  __underscores__ project here for sync_ope:

gonna replace the current ac-ac power-supply input circuit with a single supply 12v one. this is a large enough change that i should also update:

- [x] circuit price
- [ ] ~~the shop photo of circuit~~ decided this is not needed
- [ ] ~~the doodle sketch~~ decided this is not needed
- [x] the booklet
- [x] the 3d rendered image
- [x] the video-walkthrough
- [ ] anything else ?

other things (that should update every release not just major):

- [ ] release version in git
- [ ] bom - tayda/mouser/both/interactive
- [ ] schematic
- [ ] gerber zip
- [ ] diy parts sheet (this wil be manual)

cyberboy666, 2022-11-24:
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

cyberboy666, 2022-11-24:
#5

Closed 2023-02-13.

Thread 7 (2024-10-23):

replace monostable blanking stage with rp2040 blanking gen

cyberboy666, 2024-10-23:
based on my recent work using rp2040 to generate and lock to composite sync i think this would be an easier (and maybe cheaper) option than the current solution

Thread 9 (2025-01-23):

current +/-5v rail generation circuit requires >1A supply to get started

cyberboy666, 2025-01-23:

cyberboy666, 2025-06-08:
tested added the delayed start up but still no luck creating negative rail with 1A supply....

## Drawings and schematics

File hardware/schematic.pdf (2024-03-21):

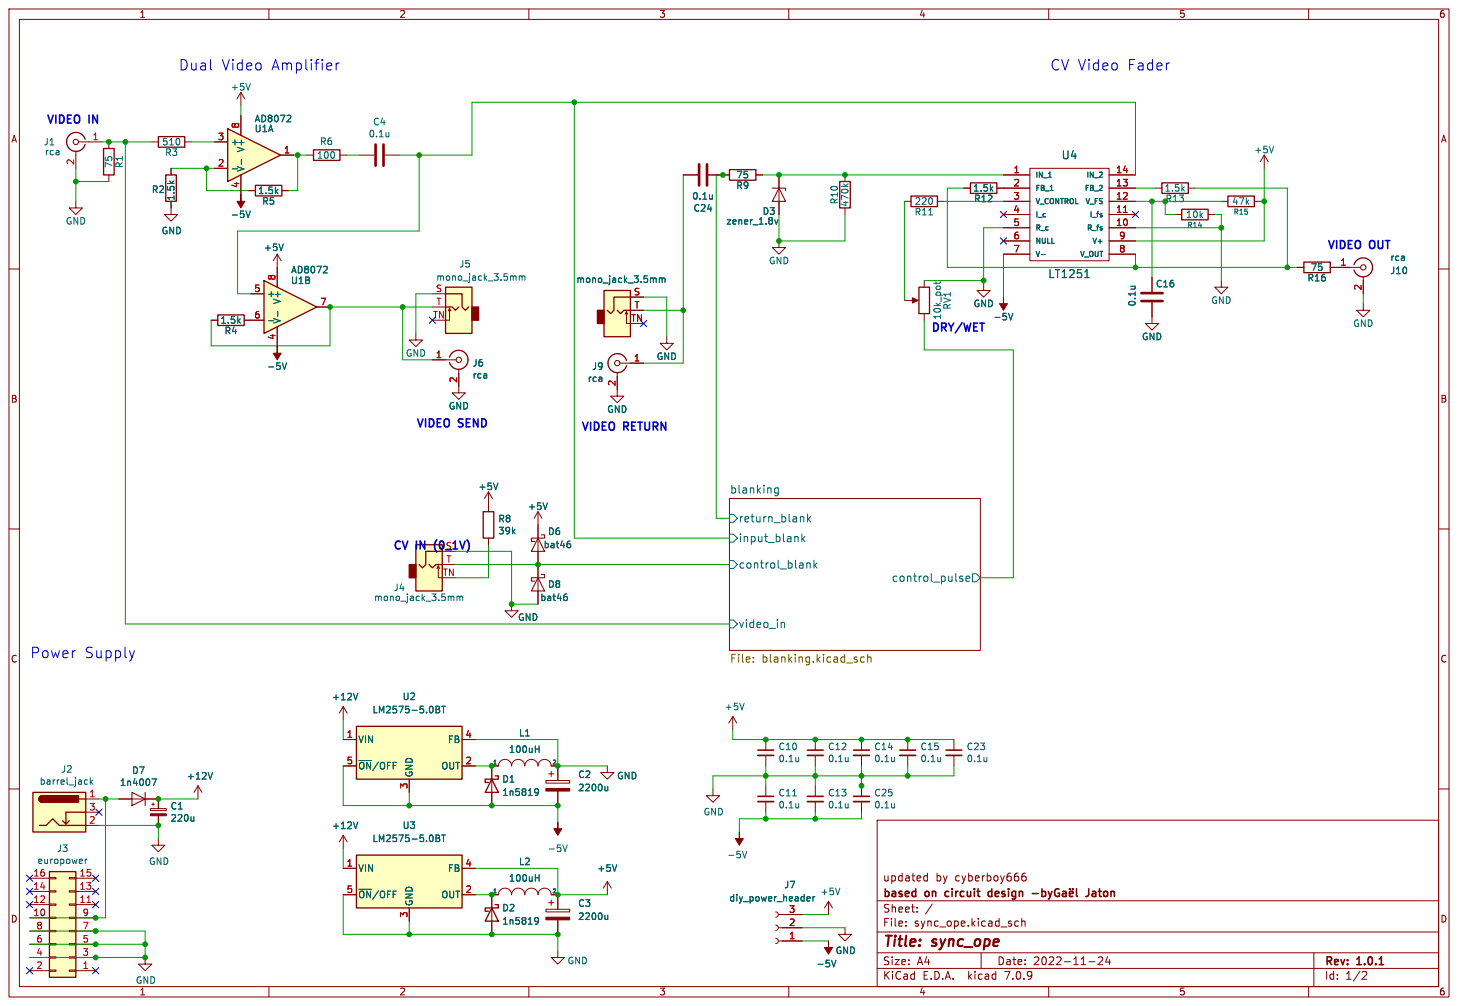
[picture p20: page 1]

0.1u 75R1 VIDEO IN Power Supply

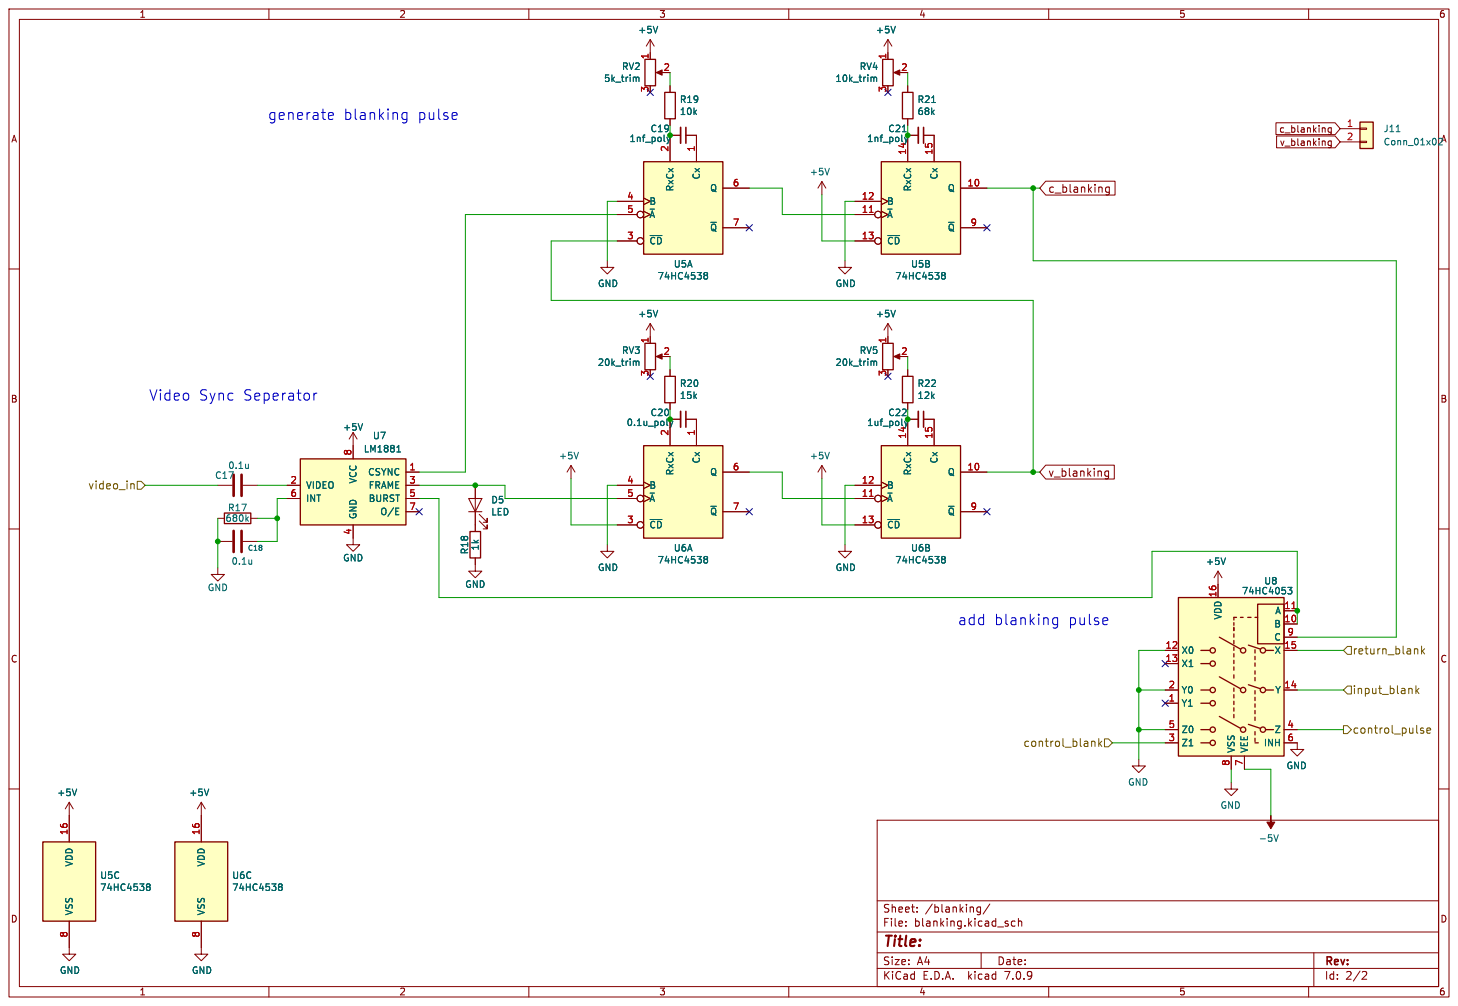
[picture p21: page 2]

Id: 2/2 Title: File: blanking.kicad_sch Sheet: /blanking/

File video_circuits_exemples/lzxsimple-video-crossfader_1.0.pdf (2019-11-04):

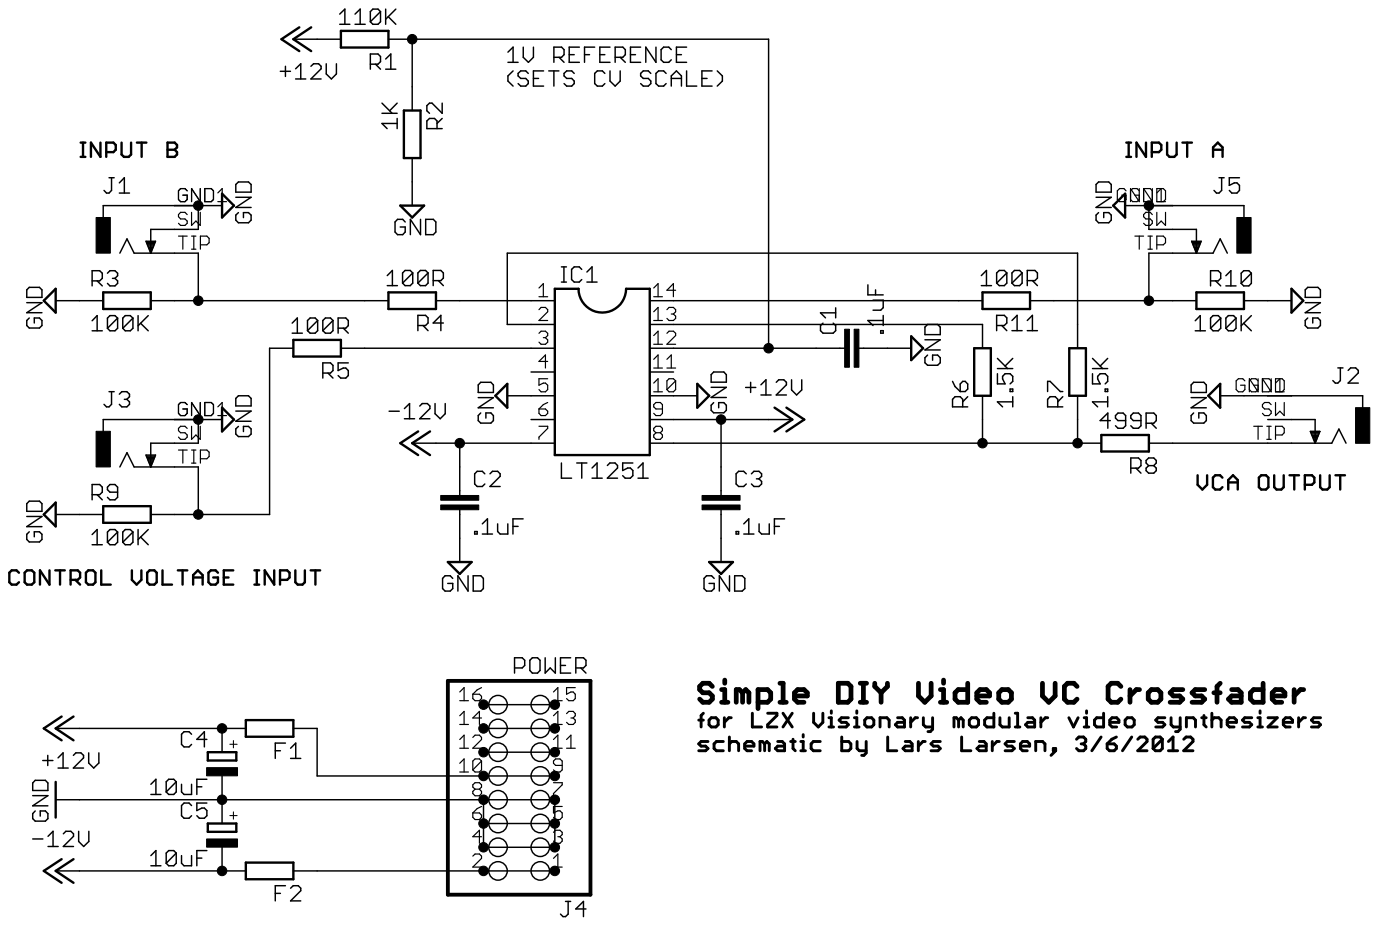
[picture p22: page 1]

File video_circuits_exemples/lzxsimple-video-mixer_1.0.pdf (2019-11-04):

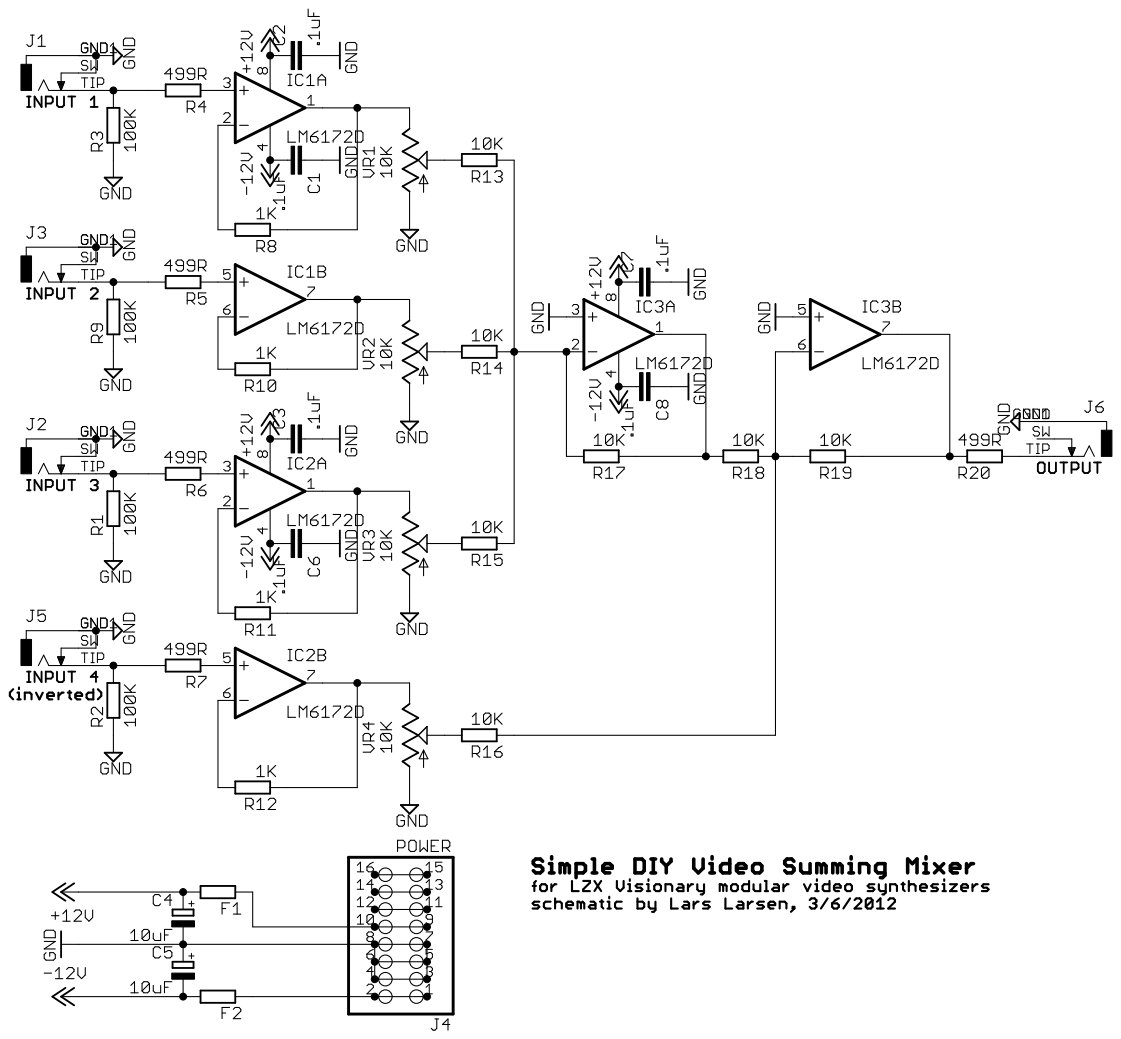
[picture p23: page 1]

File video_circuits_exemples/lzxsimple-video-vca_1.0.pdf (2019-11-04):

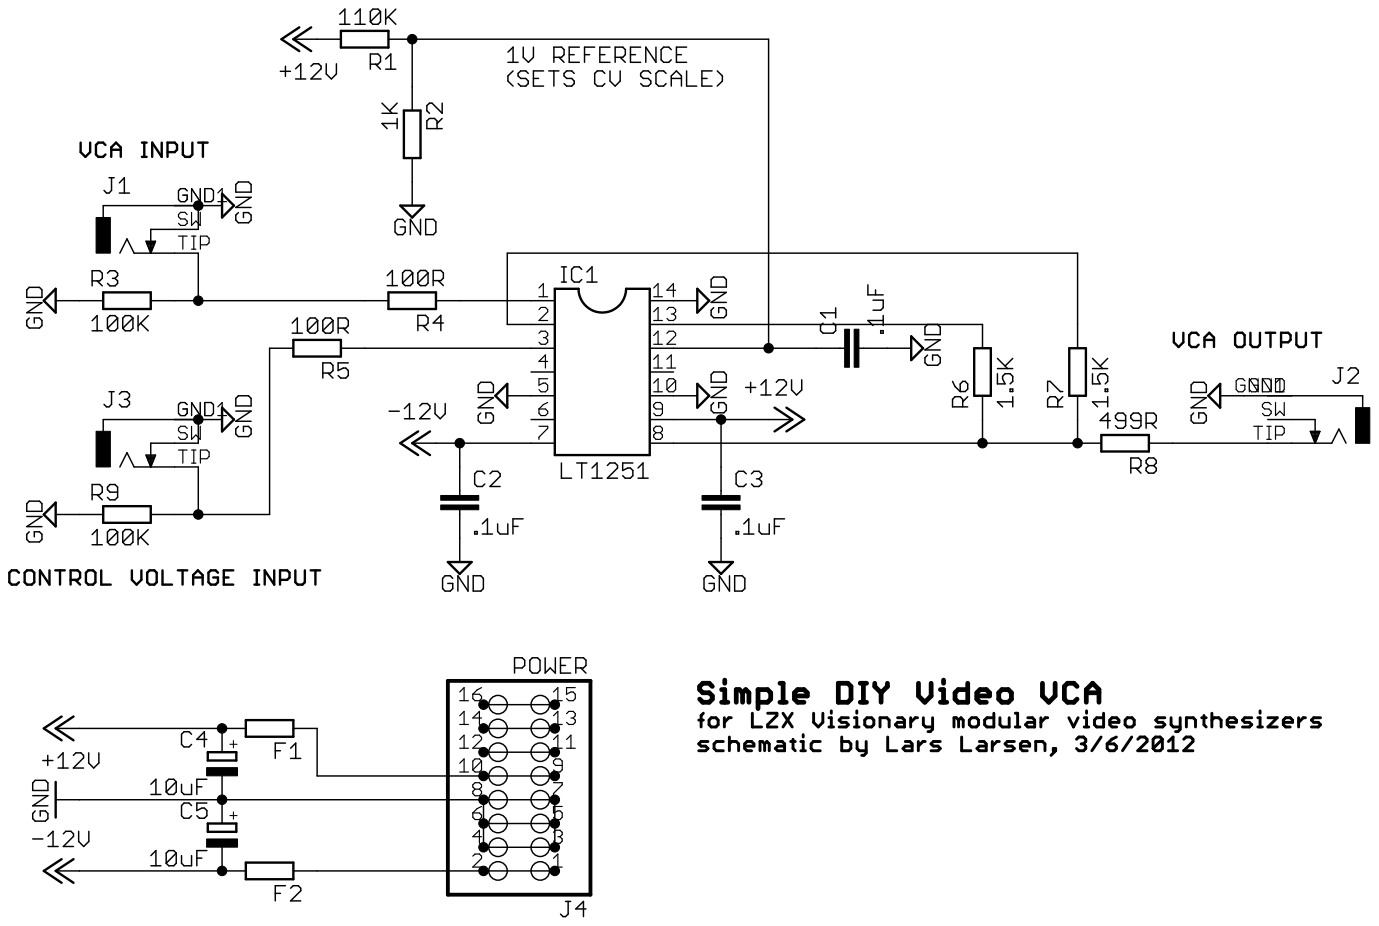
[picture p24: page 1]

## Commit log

2019-10-28 added kicad project, proto schematic
    [Sync-Ope-proto.kicad_pcb, Sync-Ope-proto.sch]
2019-11-04 wip - updating schematic, not finished
    [Sync-Ope-proto-changes.sch, Sync-Ope-proto.sch, sync-ope2.sch]
2019-11-18 print new schematic pdf
    [Sync-Ope-proto-2019-10-28-20-27-35.sch, Sync-Ope-proto.kicad_pcb, Sync-Ope-proto.sch]
2019-11-25 pcb layout first proto
    [Sync-Ope-proto-2019-10-28-20-27-35.sch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]
2020-01-05 updating schematic and pcb for 0.1proto
    [Sync-Ope-proto-B_Cu.gbl, Sync-Ope-proto-B_Mask.gbs, Sync-Ope-proto-B_Paste.gbp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]
2020-01-05 creating gerber files
    [Sync-Ope-proto-B_Cu.gbl, Sync-Ope-proto-B_Mask.gbs, Sync-Ope-proto-B_Paste.gbp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]
2020-01-10 update a trace for proto0.1 order
    [Sync-Ope-proto-B_Cu.gbl, Sync-Ope-proto-B_Mask.gbs, Sync-Ope-proto-B_Paste.gbp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]
2020-06-13 update circuit design to 0.2
    [Sync-Ope-proto-B_Cu.gbr, Sync-Ope-proto-B_Mask.gbr, Sync-Ope-proto-B_Paste.gbr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]
2020-12-01 latest revision
    [Sync-Ope-proto-B_Cu.gbr, Sync-Ope-proto-B_Mask.gbr, Sync-Ope-proto-B_Paste.gbr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]
2021-07-14 circuit revision 0.3
    [Sync-Ope-proto-B_Cu.gbr, Sync-Ope-proto-B_Mask.gbr, Sync-Ope-proto-B_Paste.gbr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]
2021-09-09 adding latest schematic
    [Sync-Ope-proto.kicad_pcb, tayda_bom_10x.csv]
2021-09-27 working on v0.4.0
    [Sync-Ope-proto.kicad_pcb, Sync-Ope-proto.sch, blanking.sch]
2022-01-11 folder refactor
    [Sync-Ope-proto-B_Cu.gbl, Sync-Ope-proto-B_Cu.gbr, Sync-Ope-proto-B_Mask.gbr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]
2022-01-31 update circuit
    [Sync-Ope-proto.kicad_pcb]
2022-02-10 plot schematic
    [Sync-Ope-proto.sch]
2022-02-23 update booklet and schematic info
2022-02-23 rename kicad project
    [Sync-Ope-proto.csv, sync_ope.kicad_pcb, sync_ope.sch]
2022-04-05 made final? fixes to the board
    [blanking.sch, full_bom.csv, mouser_bom.csv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]
2022-04-26 update ibom
    [sync_ope.csv, sync_ope.kicad_pcb]
2022-04-26 update bom
    [full_bom.csv, mouser_bom.csv, tayda_bom.csv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]
2022-08-11 fix bug with broken sync trace
    [blanking.kicad_sch, full_bom.csv, sync_ope.csv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]
2022-08-11 removed silk screen p/n markers for now
    [sync_ope.kicad_pcb]
2022-09-24 update blanking values
    [blanking.kicad_sch, full_bom.csv, sync_ope.csv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]
2022-09-26 update schematic and add booklet
    [sync_ope.kicad_pcb]
2022-10-27 add led polarity
    [sync_ope.kicad_pcb]
2022-11-14 tweak values for blanking
    [blanking.kicad_sch, full_bom.csv, sync_ope.csv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]
2022-11-24 create revision for new power circuit
    [blanking.kicad_sch, full_bom.csv, mouser_bom.csv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]
2023-04-24 update to v1_0_1 to increase range of blanking trim
    [blanking.kicad_sch, full_bom.csv, sync_ope.csv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]
2023-07-12 add panel stuff
    [back_panel-Edge_Cuts.dxf, back_panel.kicad_pcb, back_panel.kicad_sch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]
2023-10-16 fix mistake in bom
    [full_bom.csv, tayda_bom.csv, tayda_bom_10x.csv]
2024-01-22 make small fixes for colour shift / level adjust
    [blanking.kicad_sch, full_bom.csv, sync_ope.csv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]
